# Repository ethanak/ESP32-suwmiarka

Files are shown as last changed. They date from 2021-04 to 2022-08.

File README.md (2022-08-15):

# Gadająca suwmiarka na ESP32 (talking calipers)

## Disclaimer (for non-Polish users)

Synthesizer used in this project is specific to Polish language.
Please, do not ask me to add English/Russian/Chinese speech.

## Kilka uwag

W projekcie użyto kodu pochodzącego z następujących źródeł

* Odczyt i dekodowanie suwmiarki: <https://github.com/MGX3D/EspDRO>
* Audio: <https://github.com/earlephilhower/ESP8266Audio>
* Synteza mowy: <https://github.com/ethanak/ESP8266-Lektor>

Program został przetestowany z suwmiarką Vorel. Nie gwarantuję działania
z innymi suwmiarkami.

Wtyczka i szczegóły połączenia z suwmiarką - patrz <https://github.com/MGX3D/EspDRO>

Można wydrukować mniejszą wtyczkę z pliku w katalogu connector. Ustawienia druku:

* Materiał - TPU
* Średnica dyszy - 0.4 mm
* Wysokość warstwy - 0.1 mm
* Wysokość pierwszej warstwy - 0.2 mm

Zmniejszona wtyczka pasuje wyłącznie do suwmiarki Vorel!

## I kilka słów o projekcie

Projekt przeznaczony jest przede wszystkim dla osób niewidomych i słabo widzących,
ale może być przydatny również w przypadkach, gdy sposób pomiaru utrudnia lub
uniemożliwia odczyt wyświetlacza.

Projekt jest opracowany z myślą o umieszczeniu całości na suwmiarce (z tyłu za wyświetlaczem),
bez żadnych kabli łączących suwmiarkę z wolnostojącym urządzeniem lub komputerem.

Program umożliwia odczyt zarówno w milimetrach, jak i calach. W tym drugim przypadku
precyzja ograniczona jest do 1 mil (co prawda suwmiarka podaje dane z precyzją 0.5 mil, ale
mechaniczna dokładność suwmiarki czyni taką precyzję bezsensowną, a niepotrzebnie
wydłużałaby wypowiadaną kwestię). Program automatycznie rozpoznaje w jakich jednostkach
suwmiarka przekazuje dane (zgodnie z przełącznikiem inch/mm suwmiarki).

Program dodaje jednostkę (cale/milimetry) wyłącznie przy pierwszym pomiarze lub
po zmianie jednostki. W trakcie wykonywania pomiarów odczyt w milimetrach zawiera
dwie cyfry po przecinku, odczyt w calach trzy, co pozwala łatwo rozpoznać jednostkę
w której pracuje suwmiarka.

Program może pracować w trzech trybach:

* Odczyt zmian - program odczytuje wartość tylko jeśli się zmieniły lub po naciśnięciu klawisza
* Odczyt na żądanie - program odczytuje wartość po naciśnięciu klawisza
* Odczyt ciągły - program odczytuje dane cały czas w odstępach sekundowych

Przełączanie odbywa się poprzez dłuższe (powyżej pół sekundy) wciśnięcie klawisza. Tryb jest anonsowany
po każdej zmianie.

Podwójne wciśnięcie klawisza odczytuje stan baterii.

Proponowany schemat połączeń:

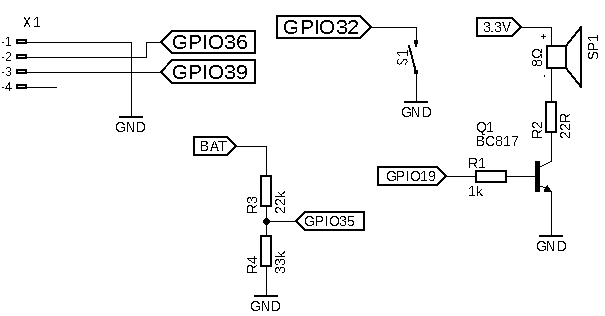
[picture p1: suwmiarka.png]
schemat Schemat układu


Tranzystor dowolny NPN o prądzie przełączania min. 0.2A. W oryginalnym urządzeniu
użyłem BC817.
Zamiast głośnika 8Ω i rezystora R2 można zastosować wysokoomowy głośnik (np. 60Ω).

Jeśli mowa jest za cicha, można zwiększyć CONTRAST_LEVEL na początku pliku audio.cpp - uzyteczne
wartości to od 0.1 do 1.0. Zwiększanie wartości powoduje zwiększenie głośności kosztem wzrostu
zniekształceń (bez zwiększania amplitudy).

Możliwe jest również użycie dowolnego smartfona lub tabletu z systemem Android jako syntezatora mowy.
W tym celu na urządzeniu z Androidem należy zainstalować aplikację Suwspiker.apk (z katalogu Android).
Aby uruchomić bluetooth w suwmiarce, należy podczas włączania trzymać wciśnięty przycisk. Po pierwszym
uruchomieniu należy sparować suwmiarkę ze smartfonem!

Większość parametrów dodatkowych można ustawić łącząc się za pomocą kabla USB
i dowolnego terminala (prędkość 115200). Polecenie ```help``` spowoduje wypisanie
wszystkich poleceń, polecenie ```help <polecenie>``` spowoduje wypisanie
pomocy dla konkretnego polecenia. Np.

```help synth```

wypisze pomoc dla polecenia ```synth``` (podłączenie zewnętrznego syntezatora)

Zdjęcia i film z użycia na forum Forbot.pl: <https://forbot.pl/forum/topic/19875-gadajaca-suwmiarka/>

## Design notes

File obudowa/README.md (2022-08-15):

# Przykładowa konstrukcja

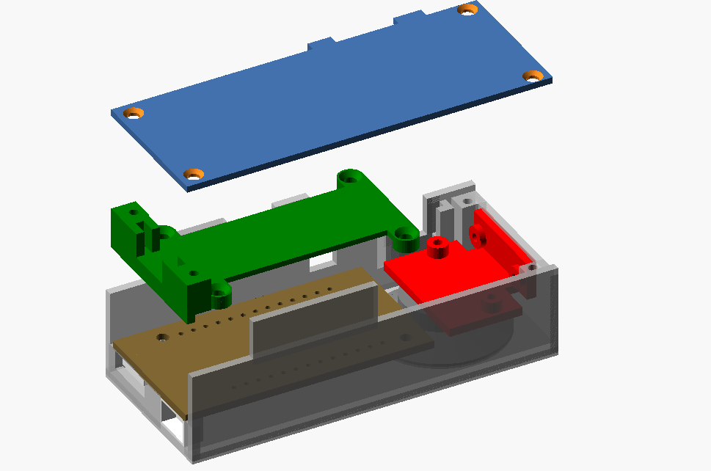
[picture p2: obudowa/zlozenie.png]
Złożenie Rysunek poglądowy


Ustawienia wydruku:
* Wysokość warstwy 0.2 mm
* Wysokość pierwszej warstwy 0.3 mm
* Wypełnienie 20%
* Skirt (bez raftu czy brimu)
* Supporty tylko dla elementu "przekladka"

Śruby M2x5mm z łbem stożkowym wkręcane bezpośrednio w przyhotowane otwory.

Użyte elementy:
* Wemos LOLIN32 LITE
* Akumulator Akyga 450 mAh 45x30x4mm
* Tact Switch 6x6mm 2-pinowy
* Przełącznik miniaturowy suwakowy 9x3.5x3.5 mm raster 2.54mm
* Miniaturowy głośnik 27mm
* Tranzystor BC817-40
* Rezystory 805

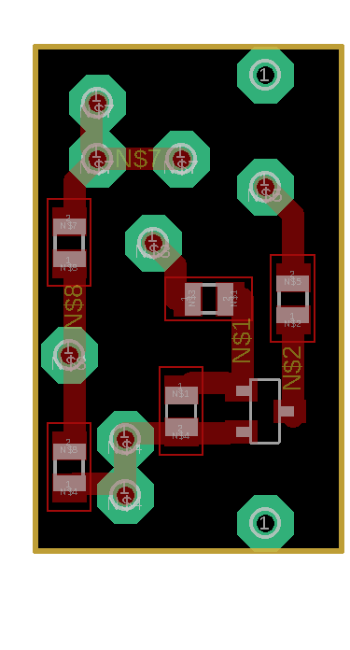
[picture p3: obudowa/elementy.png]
plytka Proponowana płytka


Płytkę należy przykręcić do uchwytu głośnika. Przełącznik i przycisk można wlutować w kawałki płytki uniwersalnej przyciuętej tak, aby pasowała do prowadnic w obudowie.

Po złożeniu i przetestowaniu należy obudowę przykleić do suwmiarki taśmą dwustronną zgodnie ze zdjęciem.
Polecam użycie pasków typu "Tesa Powerstrips".

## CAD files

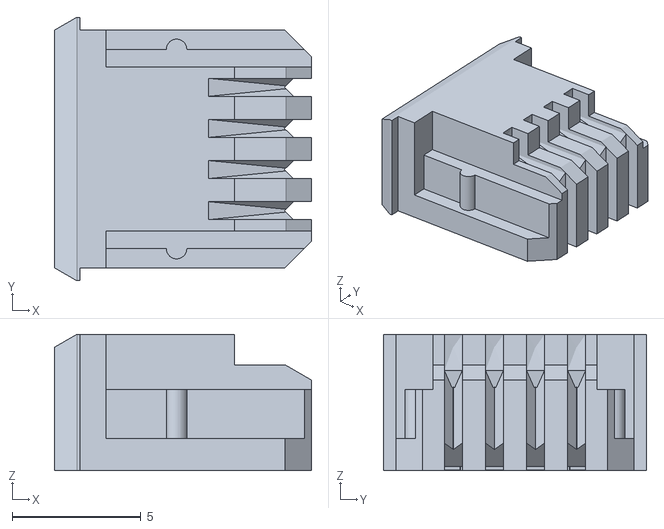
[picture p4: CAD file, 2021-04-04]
connector/mini_connector.stl
10.0 x 10.2 x 5.30

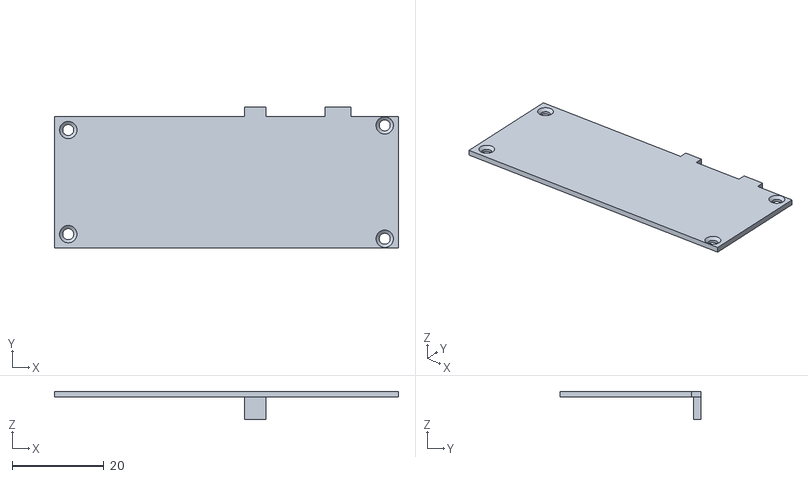
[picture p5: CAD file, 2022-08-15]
obudowa/przykrywka.stl
75.0 x 30.7 x 6.20

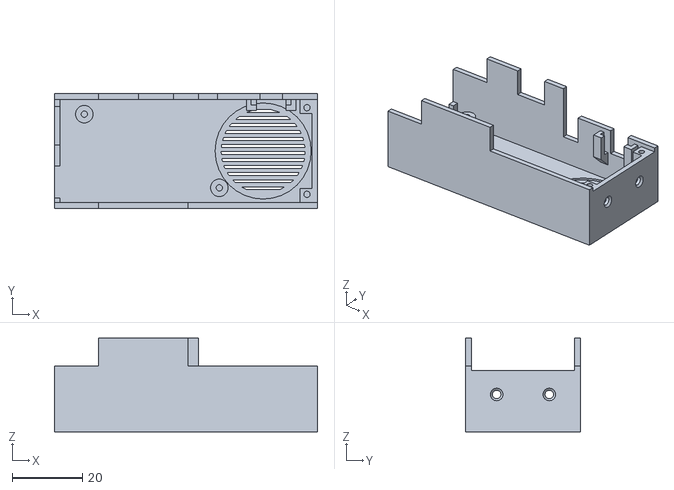
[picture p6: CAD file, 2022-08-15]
obudowa/obudowa_lo.stl
75.0 x 32.7 x 26.8

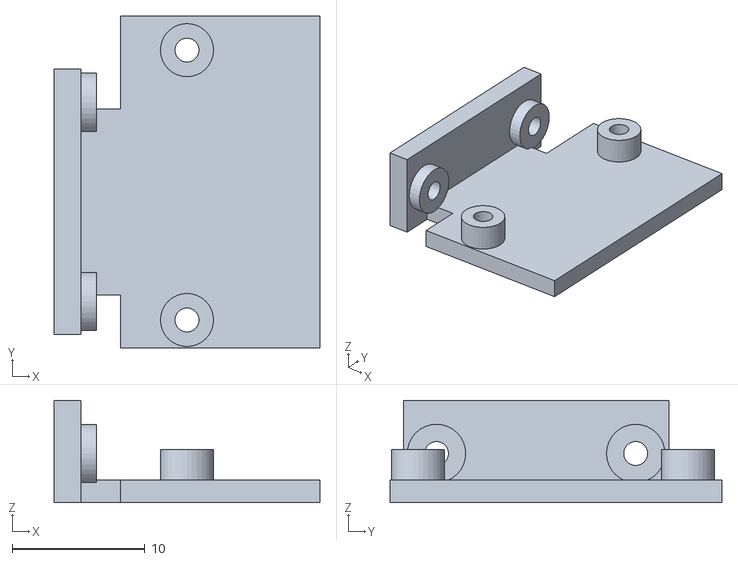
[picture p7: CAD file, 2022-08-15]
obudowa/uchwyt_glosnika.stl
20.0 x 25.0 x 7.70

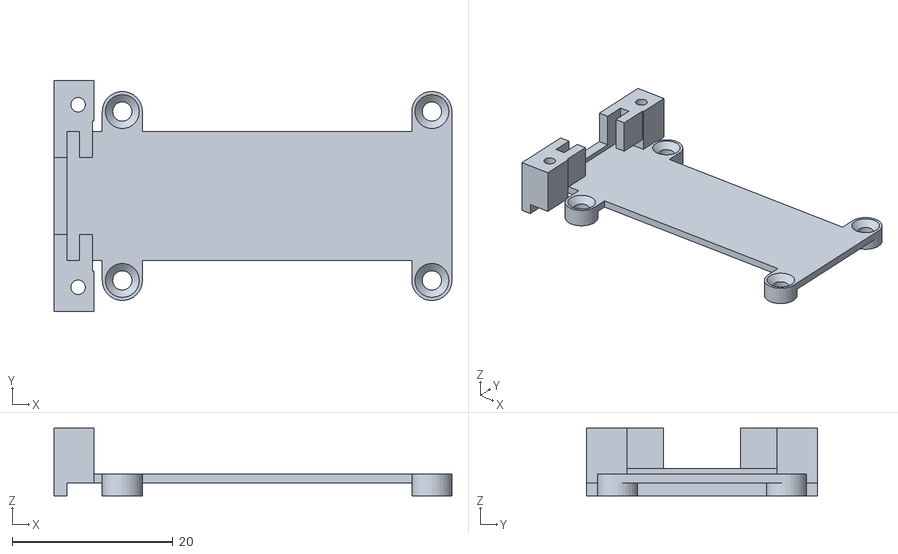
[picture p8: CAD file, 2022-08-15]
obudowa/przekladka.stl
49.5 x 28.7 x 8.40

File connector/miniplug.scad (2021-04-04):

// download spc_connector.stl from https://www.thingiverse.com/thing:3141366
module miniwtyczka()
{
    difference() {
        import("spc_connector.stl", convexity=10);
        translate([5,-10,4.1]) cube(20);
        translate([7,-10,4.1]) rotate([0,30,0]) cube(20);
        translate([-12,-10,-1]) cube([10,20,20]);
    }
}

miniwtyczka();

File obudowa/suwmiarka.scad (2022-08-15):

// Co drukujemy?
toprint = 0; // [0:obudowa, 1: przykrywka, 2: przekładka, 3: uchwyt głośnika.,4: złożenie]
// rozmiar głośnika
spkrh = 0; // [0: płaski, 1: wysoki]


module __Customizer_Limit__ () {}
$fn=32;

basew = 29.5;
baseh = 13.3;
basel = 75;

baseg = 1.3;
lpad = 27.5;
padlen = 25.5;
padh=8;

dpipx=34;
dpipl=7;
pipg=2;
upipx=[19,49, 19+42.5];

haku=5.4;

hgr=baseg+6+1+haku+2+1.2;
pipek=6.4;
xpipek=basel-pipek/2-10;
xkabel=50;

padx=[8.5, 47];
pady=[basew/2+10.5,basew/2-10.5];

module pipak(adl=0)
{
    h=baseg+hgr+14.4+adl;
    g=1.5;
    cube([dpipl-0.4,h,g]);
    translate([0,h-2,0]) cube([dpipl-0.4,2,g+2.4]);
    translate([-1.2,0,0]) {
        cube([dpipl+2.0,g+1,0.8]);
        cube([dpipl+2,hgr-5,g]);
        cube([dpipl+2,0.8,g+1]);
    }
    
}

module pipek(n=0)

{
                h=(n)?baseh+baseg-1:baseh+baseg;
                cube([dpipl-0.4,1.1,h+pipg+hgr+1]);
    echo("PIP",h+pipg+hgr+1,baseg+hgr+14.4);
    
                translate([0,0,h+hgr+1]) cube([dpipl-0.4,7,pipg]);
                translate([-1.2,0,0]) cube([dpipl+2,1.1,hgr-5]);
                translate([-1.2,0,0]) cube([dpipl+2,1.1+1.6,1.1]);

}
module obudowa(pan=3,hgl=1,grx=0)
{
    difference() {
        union() {
            translate([0,-1.6,0-grx]) cube([basel, basew+3.2, baseg+grx]);
            for (y=[-1.6,basew]) translate([0,y,0]) cube([basel,1.6,hgr+baseg]);
            for (y=[0,basew-4]) {
                translate([basel-5,y,0]) cube([5,4,hgr]);
           *     translate([0,y,baseg+7.2]) cube([5,5,hgr-7.2-baseg]);
            }
            translate([0,-1.6,0]) cube([1.6,1.6+1.4,6+baseg]);
            translate([0,10.5,0]) difference() {
                cube([1.6,basew-10,6+baseg]);
                translate([-1,16.5-10.5,2+baseg]) cube([2.7,basew-16.5-2,10]);
            }
            for (x=[/*0,*/basel-1.6]) {
                h=x?0:6+baseg;
                translate([x,-1.6,h]) cube([1.6,basew+3.2,hgr-h]);
            }
            for (i=[0,1]) translate([padx[i],pady[i],0]) cylinder(d=5,h=baseg+6);
            // wył
         *  translate([0,basew/2-8,hgr-5]) cube([4.8,16,5]); 
            // but
            translate([xpipek-7,basew-3.2,hgr-pipek-1]) hull() {
                cube([14,4.8,pipek+1]);
                translate([0,3.2,-3.2]) cube([14,1.6,1]);
            }
            // lucha
            translate([lpad-15,-1.6,hgr]) {
        //cube([padlen,2,baseg]);
        if (pan == 2 || pan == 3) {
            ex = (dpipx+dpipl-lpad+1) +
            (padlen+lpad-(dpipx+dpipl+1));
            cube([ex,1.6,padh+baseg]);
            *for (x=[0,ex-2]) translate([x,-2,-hgr]) cube([2,3,hgr+padh+baseg]);
            
        }
        else {
            cube([dpipx-lpad-1,1.6,padh+baseg]);
        //cube([dpipx-lpad-1,1.6,padh+baseg]);
            translate([dpipx+dpipl-lpad+1,0,0]) cube([padlen+lpad-(dpipx+dpipl+1),1.6,padh+baseg]);
            }
        }
                // ducha
        if (pan == 2 || pan == 3) {
        }
        else if (pan) {
            translate([dpipx-15,-2.4,0]) {
                cube([dpipl,2.4,baseh+baseg+pipg+hgr]);
                translate([0,0,baseh+baseg+hgr]) cube([dpipl,4,pipg]);
                translate([0,-0.8,baseh+baseg+hgr-2]) hull() {
                    translate([0,0,0.8]) cube([dpipl,1,pipg+1.2]);
                    translate([0,0.8,0])cube([dpipl,1,pipg+2]);
                
                }
            }
        }
        else {
            translate([dpipx-15,-3.2,0]) difference () {
                translate([-3.2,-1.6,0]) cube([dpipl+6.4,1.6+2.4,hgr]);
                    translate([-1.6,0,-1]) cube([dpipl+3.2,1.6,hgr+2]);
                    translate([0,-4,-1]) cube([dpipl,4.6,hgr+2]);
            }
        }
            // ucha
        if (pan == 2 || pan == 3) {
            translate([12.5,basew,hgr]) cube([11.5,1.6,padh+baseg]);
            *translate([12.5,basew,0]) cube([2,3.6,padh+baseg+hgr]);
            *translate([38,basew,0]) cube([2,3.6,padh+baseg+hgr]);
            translate([34,basew,hgr]) cube([7.9,1.6,padh+baseg]);
            x=upipx[2];
            if (pan == 2) translate([x-15,basew,0]) {
                difference() {
                    translate([-3.2,0,0]) cube([dpipl+6.4,1.6+4,hgr]);
                    translate([-1.6,1.6,-1]) cube([dpipl+3.2,1.6,hgr+2]);
                    translate([0,1.6,-1]) cube([dpipl,4.6,hgr+2]);
                }
            }
        }
        else if (pan) {
            for (x=upipx) translate([x-15,basew,0]) {
                h=(x>50)?baseh+baseg-1:baseh+baseg;
                u=(x>50)?1:2;
                cube([dpipl,2.4,h+pipg+hgr]);
                translate([0,-2.2,h+hgr]) cube([dpipl,5,pipg]);
                translate([0,0,baseh+baseg+hgr-2]) hull() {
                    translate([0,0,0.8]) cube([dpipl,3.2,pipg+u-0.8]);
                    cube([dpipl,2.4,pipg+u]);
                    }
                }
            }
        else {
            translate([12.5,basew,hgr]) cube([11.5,1.6,padh+baseg]);
            translate([34,basew,hgr]) cube([11.5,1.6,padh+baseg]);
            for (x=upipx) translate([x-15,basew,0]) {
                h=(x>50)?baseh+baseg-1:baseh+baseg;
                u=(x>50)?1:2;
                difference() {
                    translate([-3.2,0,0]) cube([dpipl+6.4,1.6+2.4,hgr]);
                    translate([-1.6,1.6,-1]) cube([dpipl+3.2,1.6,hgr+2]);
                    translate([0,1.6,-1]) cube([dpipl,4.6,hgr+2]);
                }
                //cube([dpipl,2.4,h+pipg+hgr]);
                }
            }
        }
        
        if (!pan) {
            for (x=upipx) translate([x-15,basew,-1]) {
                translate([-1.8,0,0]) cube([dpipl+3.6,1.6+2.4,2.1]);
            }
                translate([dpipx-15-1.8,-5.6,-1]) cube([dpipl+3.6,5.6+0.6,2.1]);
        }
        
        
        translate([xpipek-pipek/2,basew-4,hgr-pipek]) cube([pipek,14.8,pipek+3]);
        translate([xpipek-pipek/2-2.5,basew-1.6,hgr-pipek]) cube([pipek+5,1.6,hgr+1]);
        translate([xpipek-pipek/2-1,basew-4,hgr-pipek-6]) cube([pipek+2,4,14]);
        
        translate([xkabel-3-6,basew-1,hgr-7]) cube([5.5,16,26]);
        
        translate([basel-15.5,basew/2,-1]) {
            translate([0,0,-grx]) intersection() {
                cylinder(d=24,h=10);
                for (y=[-15:2:15]) translate([-15,y,0]) cube([30,0.8,10]);
                *for (x=[-5:5]) for (y=[-5:5]) translate([3*x,3*y,0]) cylinder(d=2.4,h=10);
                }
            translate([0,0,1+0.7]) cylinder(d=27.4,h=1.5);
        }
        for (x=[2.4, basew-2.4]) translate([basel-3,x,0]) {
            translate([0,0,2]) cylinder(d=1.8, h=20);
         
        }
        for (i=[0,1]) translate([padx[i],pady[i],2]) cylinder(d=1.8,h=baseg+6);
        
        for (z=[1+5+2.5+1.6]) for (y=[basew/2-7.5,basew/2+7.5]) translate([basel-2,y,z+(hgl?2.1:0)]) rotate([0,90,0]) {
            cylinder(d=2.4,h=10);
            translate([0,0,1.4]) cylinder(d1=2.4, d2=4.4,h=1.01);
        }
        
        // ucha
        
        
            if (pan == 2) {
                translate([upipx[2]-15,basew,0]) {
                    //translate([-3.2,0,0]) cube([dpipl+6.4,1.6+4,hgr]);
                    translate([-1.6,0.8,-1]) cube([dpipl+3.2,2.4,hgr+20]);
                    translate([0,1.6,-1]) cube([dpipl,4.6,hgr+20]);
                    translate([-1.6,-1.6,-1]) cube([dpipl+3.2,5,2.1]);
                }
            

            }
            else if (pan == 1) {
                for (x=upipx) translate([x-15.8,basew-1,hgr-4]) {
                    cube([0.8,4,6]);
                    translate([dpipl+0.8,0,0]) cube([0.8,4,6]);
            }
            translate([dpipx-15-0.8,-2.6,hgr-4]) {
        
                cube([0.8,4,6]);
                translate([dpipl+0.8,0,0]) cube([0.8,4,6]);
            }
       }
   }
}
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

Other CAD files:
obudowa/obudowa_hi.stl

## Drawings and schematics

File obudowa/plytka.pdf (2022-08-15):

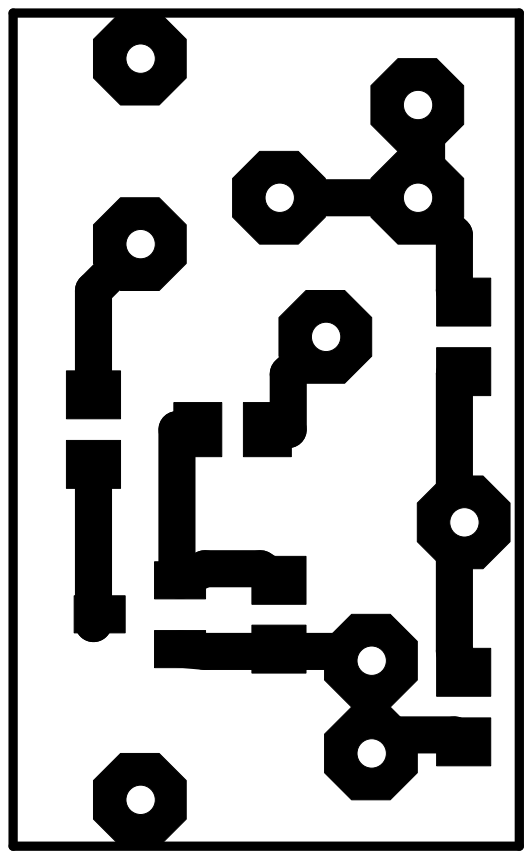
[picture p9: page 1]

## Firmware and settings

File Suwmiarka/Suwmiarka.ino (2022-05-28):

#include "Lektor2.h"
#include "prefs.h"
#include "enow.h"
#include "kbd.h"
#include <driver/adc.h>
#include <freertos/ringbuf.h>
#include <WiFi.h>

// Zakomentuj linię poniżej jeśli nie używasz bluetooth
#define ENABLE_BT 1
#define ENABLE_ENOW 1

// Tu możesz wstawić nazwę, pod którą będzie widziana suwmiarka
// w otoczeniu bluetooth
//#define BT_NAME "ESP32Suwmiarka"

#ifdef ENABLE_BT
#include "BluetoothSerial.h"
BluetoothSerial SerialBT;
bool BTActive = false;
#endif

bool ENowActive = false;

#define AUDIO_PIN 19
// BUTTON_PIN in kbd.h

/*
 * Caliper decoding code borrowed from: https://github.com/MGX3D/EspDRO
 */
 
int dataPin = 36; // yellow
#define dataChannel ADC1_CHANNEL_0
int clockPin = 39; // green
#define clockChannel ADC1_CHANNEL_3
int voltPin = 35;
#define voltChannel ADC1_CHANNEL_7

// ADC threshold for 1.5V SPCsignals (at 6dB/11-bit, high comes to around 1570 in analogRead() )
// or 390 ad 6dB/9-bit raw read
//#define ADC_TRESHOLD 800
#define ADC_TRESHOLD 200

// timeout in milliseconds for a bit read ($TODO - change to micros() )
#define BIT_READ_TIMEOUT 100

// timeout for a packet read 
#define PACKET_READ_TIMEOUT 250

// Packet format: [0 .. 19]=data, 20=sign, [21..22]=unused?, 23=inch
#define PACKET_BITS       24

// capped read: -1 (timeout), 0, 1
uint32_t mkls,dif;
int getBit() {
    int data;

    int readTimeout = millis(); //+ BIT_READ_TIMEOUT;
    while (adc1_get_raw(clockChannel) > ADC_TRESHOLD) {
      if (millis() - readTimeout > BIT_READ_TIMEOUT)
        return -1;
    }
    while (adc1_get_raw(clockChannel) < ADC_TRESHOLD) {
      if (millis() - readTimeout > BIT_READ_TIMEOUT)
        return -1;
    }
    data = (adc1_get_raw(dataChannel) > ADC_TRESHOLD)?1:0;
    dif = micros() - mkls;
    mkls = micros();
    
    return data;
}

// read one full packet
long getPacket() 
{
    long packet = 0;
    int readTimeout = millis();// + PACKET_READ_TIMEOUT;

    int bitIndex = 0;
    while (bitIndex < PACKET_BITS) {
      int bit = getBit();
      if (bit < 0 ) {
        // bit read timeout: reset packet or bail out
        if (millis() - readTimeout > PACKET_READ_TIMEOUT) {
          // packet timeout
          return -1;
        }
        
        bitIndex = 0;
        packet = 0;
        continue;
      }

      packet |= (bit & 1)<<bitIndex;
      
      bitIndex++;
    }
    
    return packet;
}

/*
 * End borrowed code
 */
 
long getResult(long packet, uint8_t *inch, uint8_t *neg)
{
  long data = packet & 0xFFFFF;
  *neg = (packet & 0x100000) ? 1 : 0;
  if (packet & 0x800000) {
        *inch = 1;
        data = data/2;
  }
  else *inch=0;
  return data;
}



Lektor2 spiker;
AudioOut audio(AUDIO_PIN);
RingbufHandle_t SpeechRB;
volatile bool audioRunning;
TaskHandle_t speechHandle;

struct spikerCmd {
    uint8_t cmd;
    char text[255];
    };
    
void speechThread(void *v)
{
    size_t itemsize;
    spiker.setAudioModule(&audio);
    struct spikerCmd *rbc;
    for (;;) {
        audioRunning = false;
        rbc = (struct spikerCmd *) xRingbufferReceive(SpeechRB, &itemsize, portMAX_DELAY);
        if (rbc) {
            audioRunning=true;
            if (rbc->cmd) spiker.say(rbc->text);
            else {
                int freq = (rbc->text[0] & 255) | ((rbc->text[1] << 8) & 0xff00);
                spiker.beep(freq);
            }
            vRingbufferReturnItem(SpeechRB, (void *)rbc);
        }
    }
}

uint8_t speaking;
void stopAudio(void)
{
    audio.stop();
    while(audioRunning) delay(10);
}

#ifdef ENABLE_BT
char btControl = 'a';
uint8_t btSpeaking;
uint32_t btSent;
uint8_t btClient=0;
void nextBT(void)
{
    if (btControl < 'a') {
        btControl='a';
    }
    else if (btControl >= 'z') {
        btControl='a';
    }
    else {
        btControl++;
    }
    //printf("Control char = %c\n", btControl);
}
void stopBTSpeaking(void)
{
    if (BTActive && SerialBT.hasClient() && btSpeaking) {
        nextBT();
        SerialBT.write(btControl);
        SerialBT.println("");
        
    }
}
#endif


void say(const char *text, bool local=false)
{
    stopAudio();
    if (!local) {
#ifdef ENABLE_ENOW
        if (ENowActive) {
            if (sayENow(text)) return;
        }
#endif
#ifdef ENABLE_BT
        if (BTActive && SerialBT.hasClient()) {
            if (pfs_extsynth == ESYN_BTA) {
                nextBT();
                SerialBT.write(btControl);
            }
            SerialBT.println(text);
            speaking = 1;
            btSpeaking = 1;
            btSent = millis();
            return;
        }
        if (sayBLE(text)) {
            speaking = 1;
            btSpeaking = 1;
            btSent = millis();
            return;
        }
#endif
    }
    struct spikerCmd rbc;
    rbc.cmd = 1;
    strcpy(rbc.text, text);
    xRingbufferSend(SpeechRB, &rbc, sizeof(rbc), 0);
    speaking=1;
}

enum {
    rmd_OnDemand = 0,
    rmd_Cont,
    rmd_Changes};
/*
enum {
    key_None = 0,
    key_Pressed,
    key_Short,
    key_Long,
    key_Double};
    
uint32_t keyTimer;
uint8_t currentKey, lastKey;
uint8_t dblmode;

enum {
    DME_NONE=0,
    DME_WAIT,
    DME_FORGET
};
*/

uint8_t readMode = rmd_Changes;


void setup(void)
{
    Serial.begin(115200);
    WiFi.mode(WIFI_MODE_NULL);
    //WiFi.mode(WIFI_STA);
    //WiFi.disconnect();
    initPrefs();
    pinMode(BUTTON_PIN, INPUT_PULLUP);
    adc1_config_width(ADC_WIDTH_BIT_11);
    adc1_config_channel_atten(ADC1_CHANNEL_0,ADC_ATTEN_DB_6);
    adc1_config_channel_atten(ADC1_CHANNEL_3,ADC_ATTEN_DB_6);
    adc1_config_channel_atten(voltChannel,ADC_ATTEN_DB_11);
    
    SpeechRB = xRingbufferCreateNoSplit(256,4);
    xTaskCreatePinnedToCore(speechThread,"speech",10000,NULL,3,&speechHandle,0);
    delay(10);
    int lkey = initKeyboardSys();
    bool esyn = false;
    
    if (!lkey || extena == 1) {
        switch(pfs_extsynth) {
#ifdef ENABLE_BT
            case ESYN_BTA:
            case ESYN_BTT: 
                SerialBT.begin(pfs_btname);
                //while(!(lastKey = digitalRead(BUTTON_PIN))) delay(10);
                say("Połączenie blutuf aktywne", true);
                esyn = true;
                BTActive = true;
                break;

            case ESYN_BLT:
                initBLE();
                say("Połączenie b l e aktywne");
                esyn = true;
                break;

#endif

#ifdef ENABLE_ENOW
            case ESYN_METR:
                ENowActive = initENow();
                if (ENowActive) {
                    say("Połączenie z metrówką", true);
                    esyn=true;
                }
                break;
#endif
            case ESYN_NONE:
            break;
            default:
            break;
        }
    }
    if (!esyn) say("Gotowy do pracy");
//        printf("\r\nI AM READY %s\r\n", WiFi.macAddress().c_str());

    extena = 0;
    speaking=1;
    delay(2000);
    waitKeyUp();
    printf("\nGotowy\n");
}

uint32_t noSignalTime;

void anounceRM(void)
{
    static const char *amd[]={"Na żądanie","Odczyt ciągły","Odczyt zmian"};
    say(amd[readMode]);
}

int rawVolt = 0;

int batpercent()
{
    static const int16_t voltlevel[]={
    3250, 3300, 3350, 3400, 3450,
    3500, 3550, 3600, 3650, 3700,
    3703, 3706, 3710, 3713, 3716,
    3719, 3723, 3726, 3729, 3732,
    3735, 3739, 3742, 3745, 3748,
    3752, 3755, 3758, 3761, 3765,
    3768, 3771, 3774, 3777, 3781,
    3784, 3787, 3790, 3794, 3797,
    3800, 3805, 3811, 3816, 3821,
    3826, 3832, 3837, 3842, 3847,
    3853, 3858, 3863, 3868, 3874,
    3879, 3884, 3889, 3895, 3900,
    3906, 3911, 3917, 3922, 3928,
    3933, 3939, 3944, 3950, 3956,
    3961, 3967, 3972, 3978, 3983,
    3989, 3994, 4000, 4008, 4015,
    4023, 4031, 4038, 4046, 4054,
    4062, 4069, 4077, 4085, 4092,
    4100, 4111, 4122, 4133, 4144,
    4156, 4167, 4178, 4189, 4200};
    int mvolt = (int)(rawVolt * pfs_mvmpx),i;
    for (i=100; i>0;i--) {
        if (mvolt >= voltlevel[i-1])  break;
    }
    return i;

}

void announceBattery(bool noinput = false)
{
    char buf[32];
    sprintf(buf,"%sBateria %d %%", (noinput?"Brak odczytu, ":""),batpercent());
    say(buf);
}

long lastPacket = 0x7fffffffL;
uint32_t lastSpoken;
uint8_t lastInch=2;
uint8_t vchanged = 0;
uint8_t anoNoSignal = 0;
uint8_t noSignalCounter = 0;
void getBattery()
{
    static uint32_t batTimer = millis() - 2000UL;
    static int bvolt = 0;
    static int nvolt = 0;
    uint32_t ms = millis();
    
    if (!nvolt && ms - batTimer < 1000UL) return;
    bvolt += adc1_get_raw(voltChannel);
    nvolt += 1;
    if (nvolt >= 16) {
        batTimer = ms;
        rawVolt = (bvolt / nvolt);
        bvolt = 0;
        nvolt = 0;
        batTimer = ms;
    }
}


void loop()
{
    uint8_t inch,neg,key;
    serloop();
    loopBLE();
    getBattery();
    key=getKey();
    if (key) {
        
        stopAudio();
#if BT_ENABLE
        stopBTSpeaking();
#endif
        if (key == key_Long) {
            readMode = (readMode + 1) % 3;
            anounceRM();
            lastPacket = 0x7fffffffL;
            vchanged = 1;
        }
        else if (key == key_Double) {
            announceBattery();
        }
        else if (speaking) {
            speaking=0;
            lastSpoken = millis();
        }
    }
#ifdef ENABLE_BT
    if (btSpeaking) {
        if (BTActive) {
            char btrcv;
            while (SerialBT.available()) {
                btrcv = SerialBT.read();
            //printf("BT received %c\n", btrcv);
                if (btrcv == btControl) {
                    speaking = 0;
                    btSpeaking=0;
                }
            }
        }
        if (btSpeaking && millis() - btSent > pfs_emillis) {
            speaking=0;
            btSpeaking = 0;
        }
        if (!btSpeaking) {
            //printf("BT Speaking finished\n");
            lastSpoken = millis();
        }
    }
    else
#endif
    if (!loopENow()) {
         if (audioRunning) {
            speaking=1;
            delay(10);
            return;
        }
            
        else if (speaking) {
            speaking=0;
            lastSpoken = millis();
        }
    }
    if (!digitalRead(BUTTON_PIN)) return;
#ifdef ENABLE_BT
    if (!btClient && BTActive && SerialBT.hasClient()) {
        btClient = 1;
        say("Połączono z suwmiarką");
        return;
    }
#endif    
    long packet = getPacket();
    if (packet >= 0) {
        //printf("%08x %d\n", packet, dif);
        anoNoSignal = 0;
        noSignalCounter = 0;
        noSignalTime = millis();
        uint8_t speak=0;
        if ((readMode == rmd_Changes)) {
            if (key == key_Short) {
                speak = 1;
                vchanged = 0;
            }
            else {
                if (packet != lastPacket) {
                    vchanged = 1;
                    lastPacket = packet;
                }
                else if (!speaking && vchanged && millis() - lastSpoken > 1000UL) {
                    vchanged = 0;
                    speak = 1;
                }
            }
        }
        else if (readMode == rmd_OnDemand) {
            if (key == key_Short) speak = 1;
        }
        else if (!speaking && millis() - lastSpoken > 1000UL) speak = 1;
        
        if (speak) {
            char buf[32],*c=buf;
            int n=getResult(packet,&inch,&neg);
            if (neg) {
                strcpy(buf,"minus ");
                c+=6;
            }
            if (inch) sprintf(c,"%d i %03d", n/1000, n%1000);
            else sprintf(c,"%d i %02d", n/100, n%100);
            if (lastInch != inch) {
                strcat(c, inch ? " cala" : " milimetra");
                lastInch = inch;
            }
            say(buf);
            lastPacket = packet;
        }
    }
    else {
        if (key == key_Short || !anoNoSignal ||
                (readMode != rmd_OnDemand && millis() - noSignalTime > ((noSignalCounter < 10) ? 10000UL:60000UL))) {
            noSignalTime = millis();
            anoNoSignal = 1;
            //say("Brak odczytu");
            if (noSignalCounter < 10) {
                say("Brak odczytu");
                noSignalCounter++;
            }
            else {
                announceBattery(true);
            }
            
        }
    }
}

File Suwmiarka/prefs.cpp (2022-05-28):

#include <Arduino.h>
#include <Preferences.h>
#include "Lektor2.h"
#include "prefs.h"
#include <WiFi.h>
#include <errno.h>

char pfs_btname[16];
int pfs_tempo;
int pfs_extsynth;
int pfs_emillis;
uint8_t enmac[6];
bool pfs_have_enmac;
bool pfs_batt;
float pfs_mvmpx; 
char pfs_uidstr[3][40];
uint8_t pfs_uid[16];
extern int rawVolt;
extern int batpercent();

Preferences preferences;
RTC_NOINIT_ATTR int extena;
extern Lektor2 spiker;

static void genUUID()
{
    esp_fill_random(pfs_uid, 16);
    pfs_uid[6] = 0x40 | (pfs_uid[6] & 0xF);
    pfs_uid[8] = (0x80 | pfs_uid[8]) & ~0x40;
    pfs_uid[7] &= 0xfc;
}

static void mkuuids()
{
    int i;
    for (i=0;i<2;i++) {
        sprintf(pfs_uidstr[i],"%02x%02x%02x%02x-%02x%02x-%02x%02x-"
             "%02x%02x-%02x%02x%02x%02x%02x%02x",
             pfs_uid[0], pfs_uid[1], pfs_uid[2], pfs_uid[3],
             pfs_uid[4], pfs_uid[5], pfs_uid[6], pfs_uid[7]+i,
             pfs_uid[8], pfs_uid[9], pfs_uid[10], pfs_uid[11],
             pfs_uid[12], pfs_uid[13], pfs_uid[14], pfs_uid[15]);
    }
}

void initPrefs()
{
    preferences.begin("suwmiarka");
    if (!preferences.getString("bt",pfs_btname,15)) strcpy(pfs_btname,"ESPSuwmiarka");
    pfs_tempo = preferences.getInt("tempo",5);
    pfs_have_enmac=preferences.getBytes("enmacspkr",(void *)enmac,6);
    pfs_extsynth = preferences.getInt("extsynth",ESYN_BTT);
    pfs_emillis = preferences.getInt("extmillis",1500);
    //pfs_batt = preferences.getBool("batt",false);
    pfs_mvmpx = preferences.getFloat("volt",2.7);
    pfs_doubleMsec = preferences.getInt("dmsec", 300);
    pfs_longMsec = preferences.getInt("lmsec", 500);
    
    /*
    if (!preferences.getBytes("bleuuid",(void *)pfs_uid,16)) {
        genUUID();
        preferences.putBytes("bleuuid",(void *)pfs_uid,16);
    }
    mkuuids();
    */
}

void pfsSetTempo(int tempo)
{
    if (tempo < 0 || tempo > 15) return;
    pfs_tempo = tempo;
    preferences.putInt("tempo",tempo);
    spiker.setTempo(tempo);
}


static char buf[1024];
static int bufpos=0;
static char *tstr;

static int getser(void)
{

    while (Serial.available()) {
        int z=Serial.read();
        if (z == 13 || z == 10) {
            if (!bufpos) continue;
            buf[bufpos]= 0;
            bufpos=0;
            return 1;
        }
        if (bufpos < 1023) buf[bufpos++]=z;
    }
    return 0;
}

static char *getToken(bool required=true)
{
    char *cmd;
    while (*tstr && isspace(*tstr)) tstr++;
    if (!*tstr) {
        if (required) printf("Brak wymaganego parametru\n");
        return NULL;
    }
    cmd = tstr;
    while (*tstr && !isspace(*tstr)) tstr++;
    if (*tstr) {
        *tstr++=0;
        while (*tstr && isspace(*tstr)) tstr++;
    }
    return cmd;
}

static int getUInt(bool required=true, int minval=0, int maxval=9999)
{
    char *t=getToken(required);
    if (!t) return -1;
    char *t1;
    
    int ival = strtol(t,&t1,10);
    if (*t1) {
        printf("Błędny zapis liczby: %s\n", t);
        return -2;
    }
    if (ival < minval || ival > maxval) {
        printf("Liczba %d poza zakresem %d .. %d\n", ival, minval, maxval);
        return -2;
    }
    return ival;
}

extern void say(const char *text, bool local=false);
static void sersayme()
{
    if (!*tstr) {
        printf("Co ja miałem powiedzieć?\n");
    }
    else say(tstr, true);
}

static void sertempo()
{
    int t = getUInt(false, 0, 15);
    if (t < -1) return;
    if (t < 0) {
        printf("Tempo %d\n", pfs_tempo);
    }
    else {
        pfsSetTempo(t);
        printf("Ustawione\n");
    }
}

static void serblu()
{
    char *name = getToken(false);
    if (!name) {
        printf("Nazwa bluetooth: %s\n", pfs_btname);
        return;
    }
    if (*tstr) {
        printf("Błąd: nazwa zwiera spację\n");
        return;
    }
    if (strlen(name) < 3 || strlen(name) > 15) {
        printf("Błąd: nazwa może mieć od 3 do 15 znaków\n");
        return;
    }
    char *c=name;
    for (c=name;*c;c++) if (!isalnum(*c) && *c != '_' && *c != '-') {
        printf("Błąd: niedozwolony znak\n");
        return;
    }
    strcpy(pfs_btname, name);
    preferences.putString("bt", pfs_btname);
    printf("Ustawione\n");
}

static void serreset()
{
    char *t=getToken(false);
    extena = (t && *t == 'e') ? 1 : 0;
    ESP.restart();
}

static void sershmac()
{
    printf("Adres MAC %s\n",WiFi.macAddress().c_str());
}



static void sermac()
{
    char *t=getToken(false);
    if (!t) {
        if (!pfs_have_enmac) printf("Adres MAC metrówki nieustawiony\n");
        else printf("Adres MAC metrówki: %02X:%02X:%02X:%02X:%02X:%02X\n",
            enmac[0], enmac[1], enmac[2], enmac[3], enmac[4], enmac[5]);
        return;
    }
    uint8_t xmac[6];
    errno = 0;
    int i;
    for (i = 0; i<6;i++) {
        if (i && *t++!=':') break;
        xmac[i] = strtol(t,&t,16);
        if (errno) break;
    }
    if (i < 6) {
        printf("Błędny adres MAC\n");
    }
    else {
        memcpy(enmac,xmac,6);
        preferences.putBytes("enmacspkr",enmac, 6);
        printf("Adres MAC metrówki: %02X:%02X:%02X:%02X:%02X:%02X, zresetuj urządzenie\n",
            enmac[0], enmac[1], enmac[2], enmac[3], enmac[4], enmac[5]);
        
    }
}

const struct syndef {
    const char *name;
    uint8_t synth;
} syndefs[] = {
    {"Brak",ESYN_NONE},
    {"Bluetooth App", ESYN_BTA},
    {"BT Classic Terminal", ESYN_BTT},
    {"BLE Terminal", ESYN_BLT},
    {"Esp-now Metrówka", ESYN_METR},
    {NULL, 0}};
    

void sersynth()
{
    char *t=getToken(false);
    int i;
    if (!t) {
        for (i=0; syndefs[i].name; i++) if (syndefs[i].synth == pfs_extsynth) break;
        if (!syndefs[i].synth) i=0;
        printf("Zewnętrzny syntezator: %s\n", syndefs[i].name);
        return;
    }
    for (i=0; syndefs[i].name; i++) if (*t == syndefs[i].synth) {
        preferences.putInt("extsynth", syndefs[i].synth);
        printf("Ustawiono: %s. Zresetuj urządznie\n", syndefs[i].name);
        return;
    }
    printf("Błędny syntezator\n");
}

void sermsec()
{
    int t=getUInt(false, 1000, 3000);
    if (t<0) {
        if (t==-1) printf("Czas czytania %d msec\n", pfs_emillis);
        return;
    }
    pfs_emillis=t;
    preferences.putInt("extmillis",pfs_emillis);
    printf("Ustawione\n");
}

void servolt()
{
    int t = getUInt(false, 3000, 4500);
    if (t < 0) {
        if (t == -1) printf("Napięcie akumulatora %d mV, %d%%\n",
            (int)(rawVolt * pfs_mvmpx),
            batpercent());
        return;
    }
    pfs_mvmpx = (float)t/(float)rawVolt;
    preferences.putFloat("volt", pfs_mvmpx);
    printf("Woltomierz skalibrowany\n");
}

static void serlong()
{
    int t=getUInt(false, 300, 1000);
    if (t < 0) {
        if (t == -1) printf("Czas %d msec\n", pfs_longMsec);
        return;
    }
    pfs_longMsec = t;
    preferences.putInt("lmsec", t);
    printf("Ustawione\n");
}
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

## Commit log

2021-04-04 Zmniejszona wtyczka pasująca do suwmiarki Vorel
    [mini_connector.stl, miniplug.scad]
2022-08-15 Dodane pliki obudowy
    [obudowa_hi.stl, obudowa_lo.stl, przekladka.stl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]
